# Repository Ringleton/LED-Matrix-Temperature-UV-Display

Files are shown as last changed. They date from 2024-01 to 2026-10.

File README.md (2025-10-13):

# Temperature and UV Index RGB Matrix Display

# Overview
This display utilizes a WIFI connection to read data from a weather server.  The display uses data produced by a Davis Instruments weather server and gets its data populated by its branded weather stations ([www.davisinstruments.com](http://www.davisinstruments.com)).  The source of the data used for this matrix display is produced by a Davis weather station set up in the Cadence neighborhood.  That station transmits data wirelessly to either a legacy data logger and/or a newer display console.  Those two systems separately upload their data to the Davis server, and it is that data that is then retrieved by the matrix display unit every 60 seconds, displaying the current temperature and UV Index.  The Davis server also maintains a web page for each station that shows the weather statistics for each.



This LED matrix display is built using a Raspberry Pi Zero 2 W, single board computer along with an Adafruit RGB matrix “bonnet” plugged into the top of the Pi.  The bonnet converts the Pi’s 3.3V output pins to 5.0V logic along with a socket to connect a cable to the input of one of the two 64 X 32 RGB LED matrix, 3mm pitch (P3) panels.

The Pi’s external connectors are exposed at the rear inset of the enclosure, along with a separate power supply connection (5V, 10A) and a pushbutton that acts as either a reboot or shutdown trigger.  You can connect a video display to the Pi’s mini-HDMI connector and a mouse / keyboard dongle to the Pi’s micro-USB On-The-Go (OTG) port to interact and control the system.  Optionally, you can also use a terminal emulator connected over WIFI.  The Pi uses a Unix-based operating system.  The program itself is written in Python.

To capture the data from the weather station, either a Davis data logger and/or station console is used.  The Davis WeatherLinkIP device is a legacy data collection device that is now obsolete.  It is one of the earlier devices that Davis employed to upload data from a weather station to their server.  As of this writing, the 6313 Console is Davis’ latest product.  This unit is an Android-based tablet display and uploads data to their server.  If both devices are employed concurrently, even though they are receiving the data being transmitted from the same physical weather station, when uploaded, the Davis server treats these as two entirely separate weather stations.  Both produce an almost identical web page summary.  You will find both a “Cadence at the Lakes” (6313 Console) and a “Cadence at The Lakes 2” (WeatherLinkIP) weather station on the Davis map with “2” being the legacy unit’s data.

While both devices upload data every 60 seconds and the corresponding web page summaries are updated immediately, the data can only be read back every 60 seconds without a paid subscription with the legacy device station.  The data from the newer console requires a paid subscription to read the data every 5 minutes or 1 minute.  Otherwise, the free subscription only provides updated data every 15 minutes.  For this reason, while the legacy device continues to work, this display is currently configured to grab that station’s data.  Until it is changed, the webpage data for station “2” and this display should be in almost perfect synchronization.

The program is designed to be able to pull data from either station so should the legacy device eventually fail or no longer be supported on their server, you can reconfigure the display to use the data uploaded from the newer console.  But note that, unless you subscribe (pay) for one of the upgraded plans, the display will show the same information for 15 minutes before it is updated (the temperature may suddenly jump several points) and the data will not be in perfect synchronization with the web page summary of this same station.
# Shutting Down or Restarting
On the rear inset panel just below the power jack, there is a pushbutton.  Momentarily press once to restart the display (takes about 60 seconds) or press and hold for at least two seconds to safely shut down the unit (takes about 20 seconds).  Whenever possible, always use the pushbutton to shut down the unit safely before disconnecting the power.  Note that when first applying power, it will take about 40 seconds before something appears on the display.
# Removing the Display from a Wall
Taking advantage of a wall with alternating vertical panel widths, extending from the rear inset area of the enclosure near the top are two levers that act as locks to prevent easy removal of the display from a wall.  To remove the display, reach from above and slide both levers fully to one side.  Note that one lever should already be pushed fully to one side so just push the other over to the same side.  You should then be able to slightly push the opposite side of the panel up and then pull away from the wall just enough until you can slide both levers fully back towards that side.  Then you should be able to pull the other side of the display slightly up and pull away from the wall and the entire display should then release.

To re-install on the wall, reverse the steps above and once completed, separate and push the one lever away from the other towards its corresponding side of the display.  If locked correctly, you should not be able to push the display upwards to then pull off the wall.

Without the locks installed, just push the entire display slightly up and then pull away from the wall.
# Username and Passwords
The username for this Pi is “cadence” and the password is “atthelakes”.  This will provide you with access to this Pi and the ability to change the WIFI network and the weather station credentials.  If the Pi username or password is ever changed, you will need to record this new information somewhere that an administrator has access to.  If the username and password above do not work, then someone may have already made that change – check with the administrator for the updated information.

The Davis Instruments account information will also need to be known by this display if the account changes or a different station is to be monitored.  The Davis Device ID or API key and secret can all be found under the Davis account.  The Davis account information will also be required to make changes to the WIFI connection of the 6313 Console.

Optionally, a free Adafruit IoT account can be used to monitor display statistics.  This Adafruit feed can be configured to provide an email notification after a configured period of inactivity.  This can alert the administrator that the display has failed or lost its internet connection.  See Adafruit IoT Monitoring below for more information.
# Connecting to the Pi
##
## With WIFI
If the Pi is connected to a WIFI network and you know it’s IP address, use the VNC Viewer application (a terminal emulator) on either a tablet or computer connected to the same WIFI network and enter the Pi’s IP address when prompted.  If you do not know the Pi’s address, you may be able to ping it or use other software to identify its IP. 
## Without WIFI
If the Pi is not connected to a WIFI network -- maybe the network has been removed or password has changed – you will need to connect directly to the Pi itself.  With the Pi removed from the wall and powered off, locate the ports on the rear inset of the display.  Connect an HDMI display to the mini-HDMI port.  Connect an On The Go (OTG) micro-USB cable to the center USB port and connect a wireless mouse / keyboard dongle to that cable.  Then, either connect the 5V, 10A power supply to the 2.1mm barrel jack port or connect a 5V, 4A power supply to the outside USB port on the Pi.  The Pi can be operated from only the USB power supply but if the RGB display is also on, the 4A power supply may not be powerful enough to drive the display and may cause the Pi to report a low voltage condition or it may just hang.

Once you have established the WIFI connection, you may want to revert to using the VNC Viewer application noted above.
# Program Configuration
The following assumes the user has basic knowledge of navigating through the Pi’s folder structure and how to edit a text file as those are beyond the scope of this document.

The display has a few user-configured options such as which Davis weather station to monitor and its operating hours.  To change the configuration, you will need to connect to the Pi using either of the methods noted above.  From the Home directory, navigate to the LED\_matrix folder.  For an existing system, in there you will find a configuration file named “config.json”.  For new installations, there is also a “config.json.sample” file that can be renamed or copied over.  The instructions for that are found further down in the [Installing the Software](README.md#Installing-the-Software) section.

Use a text editor to make any changes.  For example, from a terminal window and in the LED\_matrix folder, type: `sudo nano config.json`

The following options are found:

Property| |Description
--- | --- | ---
|`davis_weatherlinkIP_interface`||These are used for the legacy WeatherLinkIP device.
||`user`|Contrary to its name, this is the “Device ID” (DID) found under the “Device Info” screen when logged into your Davis account.  This is also shown on the back of the WeatherLinkIP device.  If this field is left blank, then the display will use the information and data from the newer console found in the next section.  If this field is not blank, then any information found in the next Console interface section is ignored.
||`password`|This is the same password you use to log into your Davis account.
|`OR_davis_console_interface`||These are for the newer 6313 Console.
||`api_key`|This key and its secret are found under your Davis “Account Information” screen, shown as “API Key V2"
||`api_secret`|
||`station_name`|This name is **case-sensitive** and set via the 6313 Console.  It is currently set to “Cadence at The Lakes”.
|`operating_hours`||Outside of the operating hours, the display will go blank and show only a blinking cursor in the lower right corner.
||`24_hours_per_day`|Set to `true` or `false`.  If false, the next two values are used.
||`on_time`|
||`off_time`|
|`dimmer`||The display can adjust its brightness based on the ambient light levels as detected by an optional light sensor found on the front edge of the display.
||`use_sensor`| If set to `true`, the sensor is used and the remaining options in this section are ignored.  The brightness of the display is adjusted every minute based on the current ambient light level.
||`max_brightness_percent`|Maximum daylight brightness setting.
||`min_brightness_percent`|Minimum nighttime brightness setting.
|`UV`||When the sun is above the horizon, the UV index can be shown on the right side of the display.  When the sun has set, only the day’s high and low temperatures are shown.  When the UV is shown, you can optionally alternate the UV index with the high and low temperatures.
||`show_UV`|Do you want UV displayed?  If you do not have a UV sensor or just don't want UV on this display, set this to `false`.
||`alternate_with_hi_lo_temp`|If set to true, during the daytime, the right side of the display alternates between the UV index and the high and low temperatures.  Otherwise, the UV index is always shown during the day.
||`hi_lo_temp_length_seconds`|During each 60 second period, this is the number of seconds that the high and low temperatures are shown instead of the UV index.
|`adafruit_IO`||The following information is optional.  A free IoT account can be created at Adafruit.com.  Every 10 minutes, this display uploads information about itself, for example, internal CPU temperature, error count and current uptime.  The Adafruit IoT feed can be configured to send an email after a configured amount of inactivity thereby alerting an administrator that the display may be down or has lost WIFI connectivity.
||`user`|Enter your Adafruit username here.
||`key`|Adafruit API key.
||`feed`|Adafruit feed name “key”.
|`locale`||Information for your locale.  Used to determine sunrise, sunset, and temperature colours.
||`latitude`|Enter your latitude here.
||`longitude`|Longitude.
||`horizon`|On the prairies, set this to 0.0 (degrees).  But if you are in a valley, you can increase this setting to best reflect the number of degrees to your horizon in order to get a more accurate sunrise and sunset for your locale.
||`really_hot`|Temperatures above this will be red.
||`really_cold`|Temperatures below this will be purple.
|`use_Celsius`||Set to `true` for Celsius or `false` for Fahrenheit

# Error Messages
If the display encounters any issues with either connectivity or the retrieved data, depending on the issue, it will attempt to automatically recover.  During the recovery period, it may display an error message.

**Network connection error.  Check WiFi.  Will retry...:** The display has lost its WIFI connection.  Check the local WIFI devices.  If WIFI is present but the error does not clear, you may need to restart the display using the optional button located on the rear of the enclosure.  Once WIFI is reestablished, the display will take up to one minute to automatically refresh.   Should you need to connect to a new WIFI network, you will need to manually connect to the Pi using the HDMI and USB connections on the rear of the display and select the new WIFI network.  See [Connecting to the Pi](README.md#Connecting-to-the-Pi) above.

**Outdated data.  Check local transmitter device**: Connectivity between this display and the Davis weather server still exists but the data being returned is more than a few minutes old.  This will also be reflected in the Davis summary web page.  This is most likely due to the local WeatherLinkIP device or the 6313 Console either being powered off or having lost their connection to their local WIFI network.  Check that device and its WIFI network - you do not need to make any changes with the display.  As soon as current data is uploaded again, the display will automatically refresh.

**Network HTTP error: ###:** This could be a server issue.  There is likely nothing you can do to correct this.  The display should recover automatically once the issue is corrected.

**Possible invalid Weatherlink username or password:**  Check the user (Device ID) or password entered in the config.json file.

**Possible invalid Weatherlink station name:** If using the Console interface, verify the weather station name.  Did you just edit it via the Console interface?  The name on the Console interface must match the name in the config.json file, and it is case sensitive.

**JSON key error: 'XXXX’ or JSON error: Expecting value: line X column Y (char Z)**: The data returned by the server is corrupt.  This is likely an intermittent problem with the server and will automatically correct itself.  There is nothing that can be done to correct this on this end. The display should recover automatically once the issue is remedied.
# Preparing the Raspberry Pi
## Installing the Operating System
Should you need to prepare a new Raspberry Pi from scratch, acquire a new micro-SD card (16Gb or more should be sufficient) and use the Raspberry Pi Imager for either a PC or Mac found here: <https://www.raspberrypi.com/software/>

When selecting the operating system, choose the “Raspberry Pi OS with desktop (Recommended)”.  

You may want to pre-edit the configuration options with a default username and password and the local WIFI username and password.  Alternatively, these settings can be edited later.   These installation notes assume a non-default user of “cadence,” but any username is fine if you adjust any reference to “cadence” to that of the user you have chosen.  Record the username and password for any future administrator.

After preparing the micro-SD card, insert it into the Raspberry Pi Zero 2 W.  Connect a mouse/keyboard dongle via a USB connector plugged into the Pi’s center USB port.  Connect a screen via the mini-HDMI connector of the Pi.  Plug a 5V power supply into the outside “PWR” USB connector and power it up.  Optionally, if the RGB matrix bonnet is already installed on top of the Pi, you can connect power to the 2.1mm barrel jack on the bonnet and the Pi will use its power.

The Pi may prompt you for some basic information and will then reboot.  It will then begin updating it’s OS to the latest version.  This may take several minutes.  When complete, it will boot up to a desktop.

If not already performed during the micro-SD card configuration, enter the network configuration area, and set up your local WIFI.

Click on the Raspberry icon on the desktop and select:  Preferences --> Raspberry Pi Configuration.

Under the Interfaces tab, ensure that I2C and optionally, VNC is enabled.  Wait for the VNC icon to appear in the upper right corner.  Reboot if you had to make any changes.

While you can continue to prepare the Pi using your directly connected monitor and mouse/keyboard dongle, if enabled above, you may want to install the Windows or Mac VNC terminal program and connect to the Pi using that.
## Installing the Software
The following steps explain how to install the necessary software for the display operation.  Detailed information about the RGB matrix bonnet and the steps to modify it by soldering a jumper can be found here: <https://learn.adafruit.com/adafruit-rgb-matrix-bonnet-for-raspberry-pi>

The LED-matrix library is copyrighted by Henner Zeller and a more in-depth explanation can be found here: <https://github.com/hzeller/rpi-rgb-led-matrix>

While you can view the links above, the software installation steps for the RGB matrix library files included in the links above are shown here…

Start a terminal window and while in the home folder, enter these commands:

`curl https://raw.githubusercontent.com/adafruit/Raspberry-Pi-Installer-Scripts/main/rgb-matrix.sh >rgb-matrix.sh`

`sudo bash rgb-matrix.sh`

When prompted, select the Adafruit RGB Matrix Bonnet and the Qualtity option.  As noted in their instructions, this step will take several minutes to complete.  The system will prompt you to reboot.

As we are using a jumper to implement the “quality” option on the RGB matrix (see the learn.Adafruit.com link above), the sound card in the Pi must be disabled so as not to interfere.  After the system has rebooted, start a terminal window again and type the following:

`sudo nano /boot/config.txt`

In this file, look for the line containing “dtparam”.  If necessary, edit this line so that it reads:

`dtparam=audio=off`

Press CTRL-X to exit the editor and if changes were made, confirm “Save modified buffer”.

With the latest OS, it is necessary to further disable the sound card by entering the following commands:

`cat <<EOF | sudo tee /etc/modprobe.d/blacklist-rgb-matrix.conf`

\> `blacklist snd_bcm2835`

\> `EOF`

`sudo update-initramfs -u`

You will need to reboot again for the changes above to take effect.

Now that the RGB library files are installed, we will install our Python programs.  After rebooting, start a terminal window again and while in the home folder, enter the following commands:

`git clone https://github.com/Ringleton/LED-Matrix-Temperature-UV-Display.git ./LED_matrix`

`cd LED_matrix`

`sudo pip install -r requirements.txt`

It is now necessary to create a configuration file.  While still in the LED\_matrix folder, type:

`cp config.json.sample config.json`

Edit this file by typing:

`sudo nano config.json`

See the [Program Configuration](README.md#Program-Configuration) section above to make the necessary changes.  Once completed, press CTRL-X to exit the editor and save your changes.

Before setting up the automatic start feature for the display and optional reboot/shutdown button, test the program now by manually launching it.  While you are still in the LED\_matrix folder, type:

`sudo python temp_display.py`

If everything is working correctly, after a few seconds, you should see temperatures shown in the display.  If any error messages appear, you will need to address them.  They will appear on the screen when the program is run interactively but some will also be placed into a file named “logfile.log”.  This log file contains information messages, warning and errors and is overwritten each time the program is started.

To manually terminate the program, press CTRL-C.

NOTE: When launching the program, you may see a warning message suggesting editing the /boot/cmdline.txt file and adding “isolcpus=3” to the very end.  If you see that, from a terminal window, type the following command:

`sudo nano /boot/cmdline.txt`

At the very end of the single line, add a space, followed by `isolcpus=3`

Press CTRL-X to exit and save the file.

You will need to reboot for this change to take effect.  Then see if the warning message has cleared by manually launching the program again from a terminal window:

`cd ~`

`cd LED_matrix`

`sudo python temp_display.py`

# Automatic Start Files
The display also includes a pushbutton that can be used to reboot or shutdown the Pi safely without having to first connect to it.  The monitoring of this pushbutton is performed by a separate program in case the main display program terminates or becomes non-responsive.  

If you want the rear button enabled to allow reboot / shutdown capability, you will need to edit the rc.local file.  From a terminal window, type:

`sudo nano /etc/rc.local`

Immediately above the “exit 0” line, add:

`python /home/cadence/LED_matrix/restart_shutdown.py &`

**Or, if you prepared the Pi using the default "pi" username, type this instead:**

`python /home/pi/LED_matrix/restart_shutdown.py &`

Don’t forget the space and ampersand at the end of the line.  Press CTRL-X to exit and save the file.

To test this, reboot the Pi.  Once it has rebooted, try momentarily pressing the pushbutton on the back of the display enclosure.  The Pi should reboot.  Pressing and holding the button for at least two seconds will cause the Pi to shutdown.  Allow at least 20 seconds before disconnecting the power.

To make the main display program automatically start every time the Pi is powered up or rebooted, you will need to create an autostart file.  Before proceeding, ensure that the display program is running correctly when invoked manually as shown above.

Then from a terminal window, type the following lines:

`cd ~`

`cd .config`

`mkdir autostart`

`cd autostart`

`sudo nano display.desktop`

Enter the following lines:
```
[Desktop Entry]

Type=Application

Name=Display

Exec=bash -c 'cd /home/cadence/LED_matrix && sudo /usr/bin/python /home/cadence/LED_matrix/temp_display.py'
```
**Or, if you prepared the Pi using the default "pi" username, for the last line, type this instead:**

`Exec=bash -c 'cd /home/pi/LED_matrix && sudo /usr/bin/python /home/pi/LED_matrix/temp_display.py'`

Don't forget to include the single quote at the very end of the line!

Press CTRL-X to exit and save your changes.  

To test your autostart file, reboot the Pi – you can use the pushbutton if enabled above – and confirm that the display automatically starts.  It may take up to a minute before you see anything in the display.
# Adafruit IoT Monitoring
The display includes the optional ability to upload internal statistics to an Adafruit IoT feed.  You can set up a free Adafruit account and create a feed.  You can configure the Adafruit feed to provide an email notification after a period of inactivity or when the CPU temperature is exceeded.  This can alert an administrator that the display is down, has lost its WIFI connection or running hot - possible blocked vents or defective fan.

Enter your account and feed information into the config.json file as noted above in the [Program Configuration](README.md#Program-Configuration) section.  The following information is sent to the feed:

**CPU T:**	The internal CPU temperature.  The Pi will withstand temperatures up to 85 degrees Celsius.  As it gets closer to its upper limit, the system will automatically begin to throttle the processor down to try to help the CPU cool back down.

**Err:**  The total number of errors encountered since the program was started.  The program is designed to automatically recover from most errors that it encounters.

**Up:**  The total number of days that the program has been running.

**Mem Use:**  The total percentage of used memory.

**Light:**  The light level from the sensor or -1 if not found.

**Brightness:**  The display brightness percentage level.  Based on either the optional light sensor or the configuration settings with the time of day.

Note: If you are connected to the Pi while the display program is running, pressing the Space Bar will temporarily show the statistics above on the display.
# 3D Files and Display Assembly
This project is published on github.com.  Included in the source code is a folder containing the 3D print files for the display enclosure.  You can either grab these files from the “3D-files” folder on the Pi after the software installation is completed or you can download the files from this link:

<https://github.com/Ringleton/LED-Matrix-Temperature-UV-Display>

The enclosure was printed using ABS print filament which provides UV protection.  There are a total of 15 mounting holes used for the 3 back panels.  Those holes are designed to accept M3 X 3mm brass heat-set inserts.  The main enclosure is available in a full print size but there are also separate left and right files in case your 3D printer cannot support the full size.

There are corresponding 3D files both with and without ventilation panels and a fan insert.  For outdoor use, it is strongly recommended to use the enclosure with ventilation panels along with the optional fan.  These ventilation panels include an internal slot to insert a screen mesh to prevent bugs and other debris from getting inside.  These ventilation panels may need to be occasionally cleaned to remove accumulating debris.

# Optional Light Sensor, Shutdown Button, and Fan
The optional VEML7700 light sensor and restart / shutdown pushbutton are connected to a header on the RGB bonnet – see photos below.  These connect to a 3 X 2 header that is connected to the bonnet's six breakout holes located immediately beside the power jack.  A light tunnel from the front of the display to the sensor is created by inserting a short length of 1/8" acrylic rod into the hole on the left side of the enclosure.

The restart / shutdown button has one side of the pushbutton connected to ground while the other side connects to GPIO 19 (pin 35) on the Pi itself.

For outdoor use, the panel's interior temperature can increase significantly, especially when in direct sunlight.  To protect the CPU from overheating, it is recommended to use the enclosure with ventilation panel and install a fan into the fan insert.  The fan can be connected directly to the ground / 5V supply causing it to operate 24/7.  

Optionally, you can install a fan switch controller and have the fan only operate when the internal CPU temperature reaches a specified level.  This will increase fan life and decrease the debris build-up on the vents.  I used a fan controller made by "8086 Consultancy".  An extra ground line is connected to the controller along with 5V and GPIO 14 via the unused connections on the 3 X 2 header on the bonnet.  The fan is then plugged into the output of the controller.  To enable the fan action, click on the Raspberry icon on the desktop menu and select: Preferences --> Raspberry Pi Configuration --> Performance and then enable the fan, set the Fan GPIO to 14 and the "on" temperature.  I used a setting of 69 so that any CPU temperatures at or above 70 will trigger an email alert.

Looking from the top of the bonnet with the connector towards the right:

|||||
| :- | :- | :- | :- |
|Top Row|<p>Black VEML7700</p><p>Ground</p>|<p>Red VEML7700</p><p>3\.3V</p>|<p>*Optional 5V to fan</p><p>or to fan controller</p>|
|Bottom Row|<p>*Optional fan enable</p><p>to fan controller input</p>|<p>Yellow VEML7700</p><p>SCL</p>|<p>Blue VEML7700</p><p>SDA</p>|









# Parts List

|**Part Description**|**Supplier**|**Part #**|**Qty**|
| :- | :- | :- | :- |
|Raspberry Pi Zero 2 W|Adafruit|5291|1|
|Break-away 0.1" 2x20-pin Strip Dual Male Header|Adafruit|2822|1|
|Micro-SD card|||1|
|64x32 RGB LED Matrix panels - 3mm pitch|Adafruit|2279|2|
|RGB Matrix bonnet for Raspberry Pi|Adafruit|3211|1|
|2x8 IDC ribbon cable, 12"|Adafruit|4170|1|
|Right angle VEML7700 light sensor|Adafruit|5378|1|
|STEMMA QT / Qwiic JST SH 4-pin Cable with<br>Premium Female Sockets - 150mm Long|Adafruit|4397|1|
|5V 10A switching power supply|Adafruit|658|1|
|Right angle 2x3 connector header|DigiKey|952-2092-ND|1|
|2\.1mm power plug with cable|DigiKey|839-1246-ND|1|
|Connector jack panel mount 5.5x2.1mm|DigiKey|839-1580-ND|1|
|Pushbutton switch SPST-NO 3A|DigiKey|EG1900-ND|1|
|*Optional* Axial fan 30 X 8mm 5VDC|DigiKey|1528-1904-ND|1|
|*Optional* Fan controller|PiShop.ca|1915|1|
|*Optional* Pi4 heat sink set (use the lowest profile heat sink)|DigiKey||1|
|3D-printed enclosure|||1|
|M2.5 & M3.0 nuts/bolts/spacers|||1|
|M3 X 3mm heat set inserts|Adafruit|4256|15|

# Davis Weather Station Devices and Account Information
The weather station at Cadence uses the following Davis Instruments devices:

- Wireless Vantage Pro 2 Weather Station 6252
- Solar-powered wireless sensor transmitter 6332 (used for the anemometer)
- Solar radiation sensor 6450
- UV sensor 6490
- WeatherLinkIP data logger / transmitter 6555
- WeatherLink Console 6313

The data is uploaded to the Davis WeatherLink.com site and this matrix display uses the Davis API to grab that data from their servers.  See the [Overview](README.md#Overview) section at the beginning of this document for more information.

Anyone can set up a free Davis account where you can monitor weather stations from around the world.  Optionally, you can upload weather data from  your weather station and share it with others.  At the time of this writing, both a legacy 6555 WeatherLinkIP data collector and the newer Davis 6313 Console are both being employed to upload data for Cadence and are treated as two separate weather stations even though the data for each is being transmitted by a single physical station device.

One advantage of the legacy device is that you can download the data via the API and that data is up to the minute, even with a non-subscription account.  Using the data from the newer console is available up to the minute only with a paid subscription.  Otherwise, that data is only updated every 15 minutes.

The legacy device plugs into a network router with a wired connection.  You can configure it using the Davis WeatherLink software for either Windows or a Mac.  This software download is available from Davis if you are logged in with your free Davis account.  Note that the software is very outdated but still works.  On a Windows system, you may have to “Run as Administrator”.

The newer Console connects to your local network over WIFI.  The configuration of that is performed through the Console itself using your Davis account username and password.

Weather station data from around the world is uploaded to the Davis server.  You can access your data and that of other stations via the WeatherLink.com site, your display console or the Davis Weather app, also available for free download.

When logged into your Davis account on the weatherlink.com website, you can also let someone see your weather station data via various URL’s without them needing to sign up for a Davis account.  You can access these URL’s via the “Share and Uploads” button under your account.  At the time of writing, one of those URL’s for the weather station data being sent by the console at Cadence is: <https://www.weatherlink.com/embeddablePage/show/17a85d105372405483298eef95e886b6/summary>

If later, a new Davis account is created and the physical weather station devices are moved over to that account, the URL links will likely also change.

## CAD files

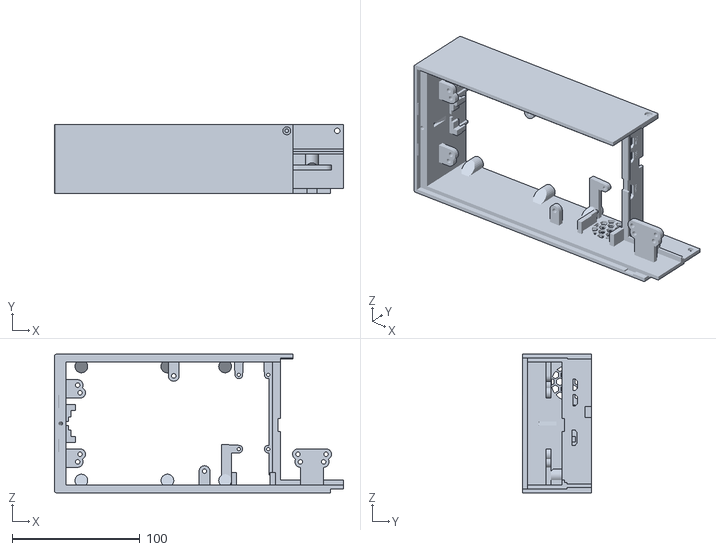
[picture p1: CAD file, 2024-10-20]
3D_files/Dual Matrix Main Enclosure Left with Vents.stl
225.8 x 54.0 x 108.4

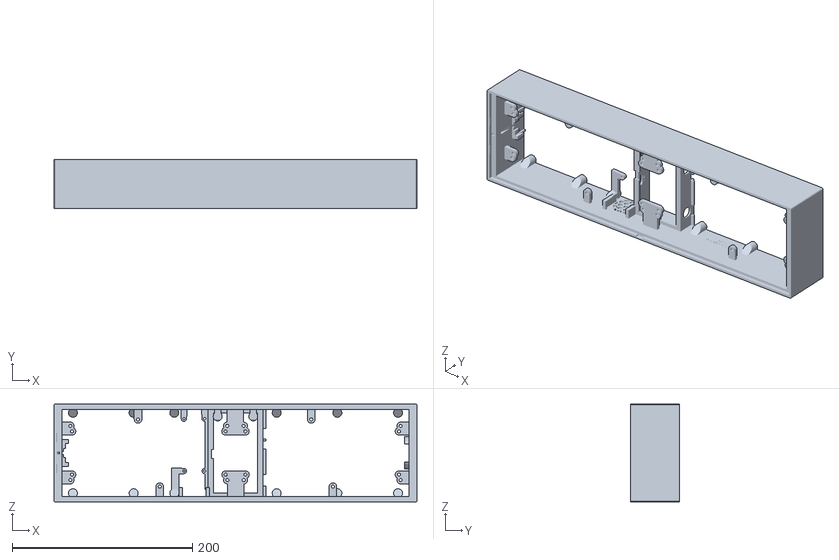
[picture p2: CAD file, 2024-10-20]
3D_files/Dual Matrix Main Enclosure One Piece with Vents.stl
402.3 x 54.0 x 108.4

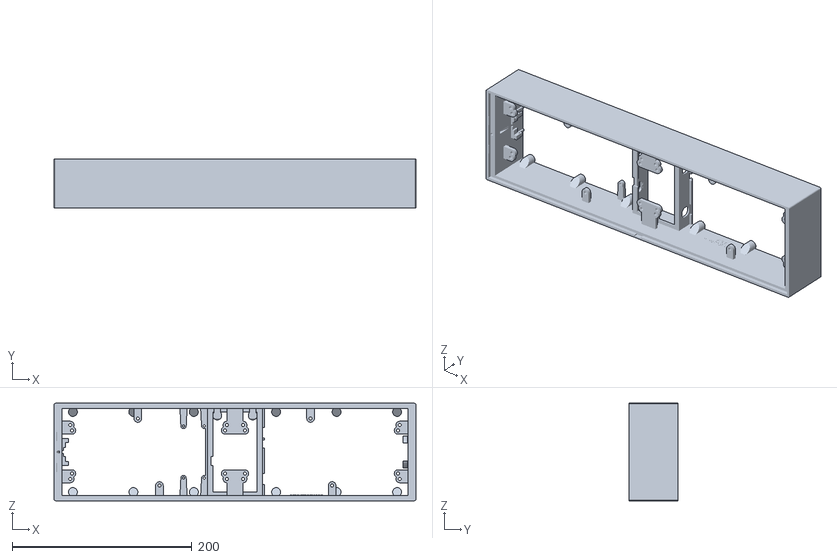
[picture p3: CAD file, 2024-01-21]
3D_files/Dual Matrix Main Enclosure One Piece.stl
402.4 x 54.0 x 108.4

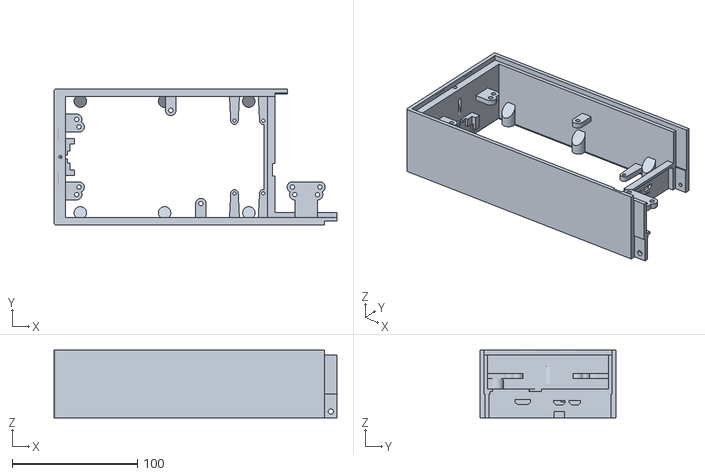
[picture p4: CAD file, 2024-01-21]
3D_files/Dual Matrix Main Enclosure Left.stl
225.8 x 108.4 x 54.0

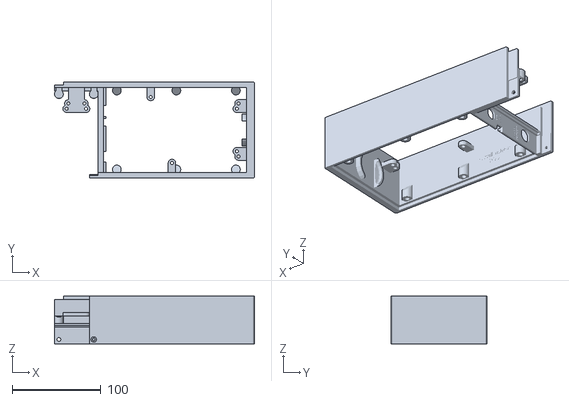
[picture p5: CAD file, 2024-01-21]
3D_files/Dual Matrix Main Enclosure Right.stl
225.9 x 108.4 x 54.0

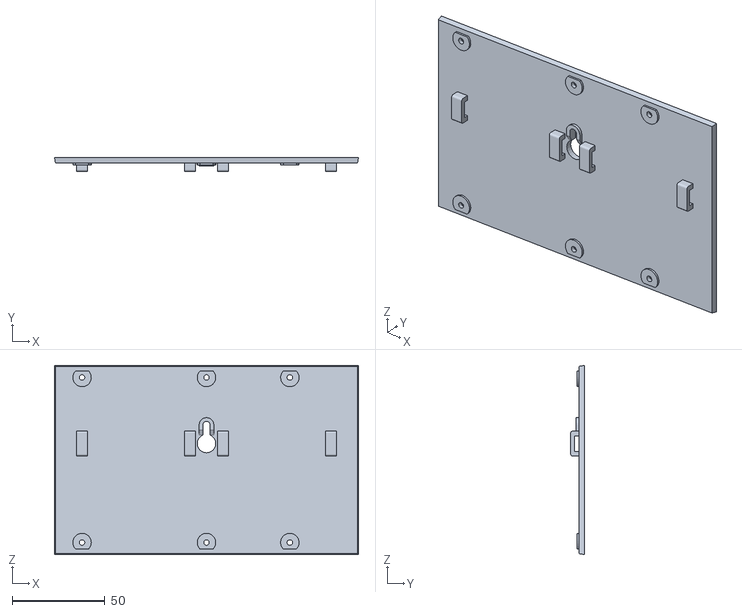
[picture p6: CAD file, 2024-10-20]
3D_files/Dual Matrix Large Back Panel - Vent Side.stl
164.3 x 7.40 x 102.2

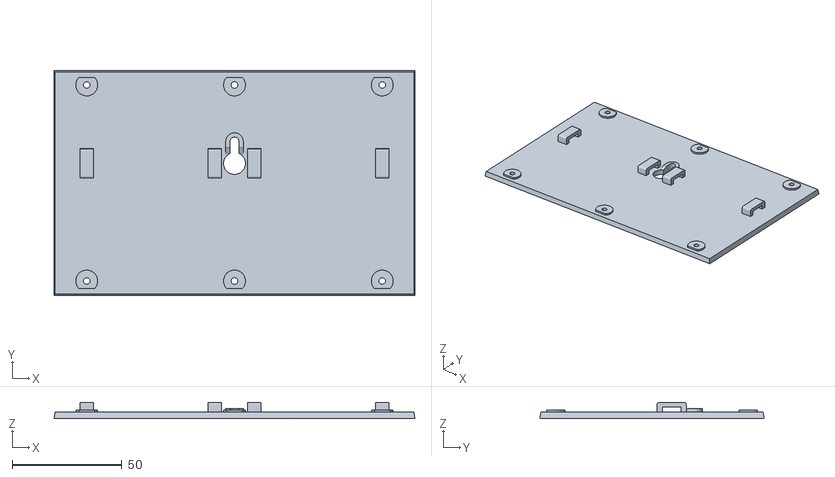
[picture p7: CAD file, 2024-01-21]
3D_files/Dual Matrix Large Back Panel.stl
164.3 x 102.2 x 7.40

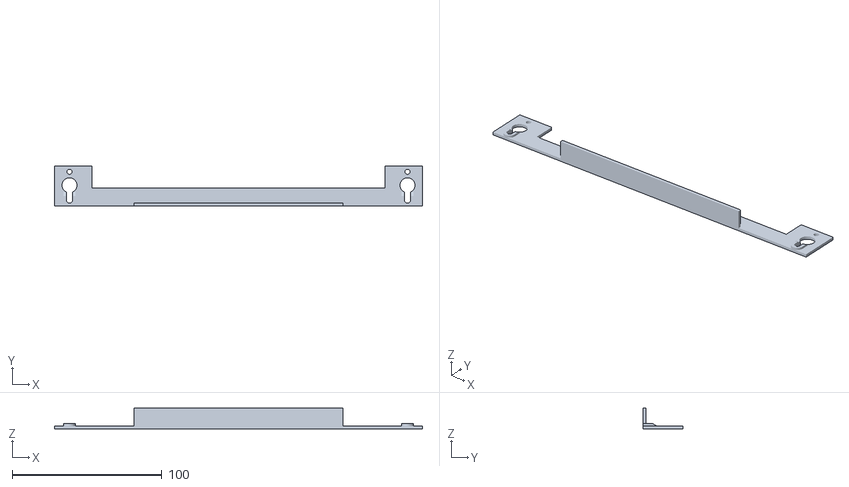
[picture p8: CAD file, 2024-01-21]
3D_files/Dual Matrix Mounting Template.stl
245.9 x 27.0 x 14.0

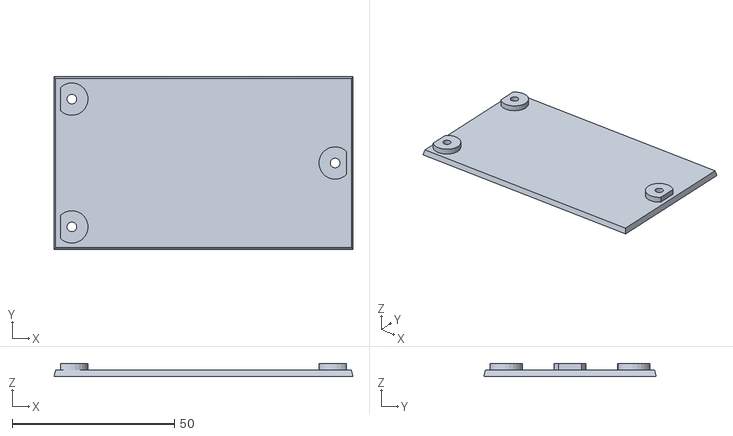
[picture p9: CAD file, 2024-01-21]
3D_files/Dual Matrix Small Back Panel.stl
92.2 x 53.2 x 4.00

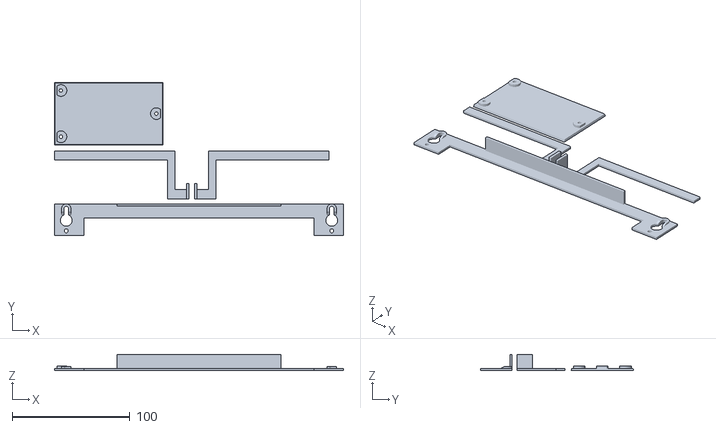
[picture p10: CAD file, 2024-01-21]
3D_files/Dual Matrix Misc Parts.stl
245.9 x 130.4 x 14.0

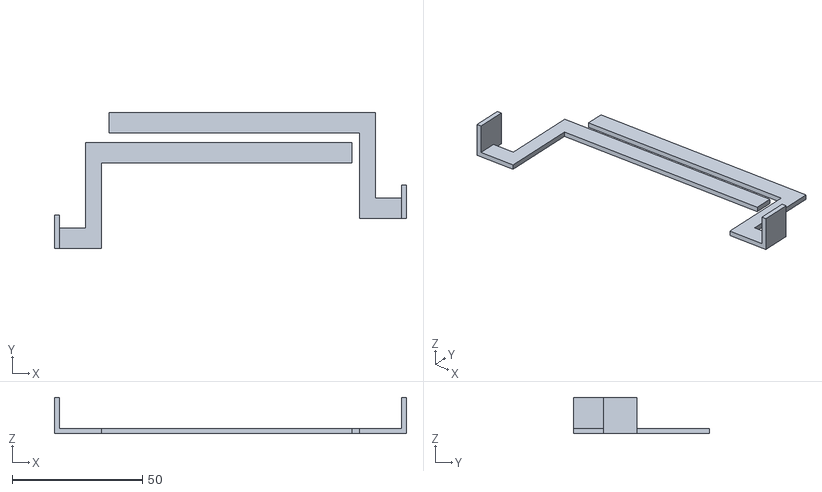
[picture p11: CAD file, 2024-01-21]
3D_files/Dual Matrix Mounting Locks.stl
135.3 x 52.4 x 14.0

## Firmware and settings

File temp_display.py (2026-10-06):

# LED matrix temperature / UV display

# MIT License
# Copyright (c) 2026 by Russell Ingleton

from time import sleep
from datetime import datetime
import os
import sys
import json
import colorsys
import ryb2rgb
import requests
from requests.exceptions import ConnectionError
import threading
import argparse
from rgbmatrix import RGBMatrix, RGBMatrixOptions, graphics
import board
import adafruit_veml7700
import busio
import ephem
import textwrap
import logging
import shutil
import subprocess

# All of these are for various testing
import pynput
from pynput import keyboard 
import functools
import psutil  # for memory testing
from gpiozero import CPUTemperature  # for testing.  CPU temperature monitoring

# For Adafruit IoT feed that montiors CPU temp but also acts as a warning
# if the feed stops receiving information
from Adafruit_IO import Client, RequestError


def args():
    parser = argparse.ArgumentParser()

    # Options for the rpi-rgb-led-matrix library
    parser.add_argument("--led-rows", action="store", help="Display rows. 16 for 16x32, 32 for 32x32. (Default: 32)",
                        default=32, type=int)
    parser.add_argument("--led-cols", action="store", help="Panel columns. Typically 32 or 64. (Default: 64)",
                        default=64, type=int)
    parser.add_argument("--led-chain", action="store", help="Daisy-chained boards. (Default: 2)", default=2, type=int)
    parser.add_argument("--led-parallel", action="store",
                        help="For Plus-models or RPi2: parallel chains. 1..3. (Default: 1)", default=1, type=int)
    parser.add_argument("--led-pwm-bits", action="store", help="Bits used for PWM. Range 1..11. (Default: 11)",
                        default=11, type=int)
    parser.add_argument("--led-brightness", action="store", help="Sets brightness level. Range: 1..100. (Default: 100)",
                        default=100, type=int)
    parser.add_argument("--led-gpio-mapping", help="Hardware Mapping: regular, adafruit-hat, adafruit-hat-pwm",
                        default='adafruit-hat-pwm', choices=['regular', 'adafruit-hat', 'adafruit-hat-pwm'], type=str)
    parser.add_argument("--led-scan-mode", action="store",
                        help="Progressive or interlaced scan. 0 = Progressive, 1 = Interlaced. (Default: 1)", default=1,
                        choices=range(2), type=int)
    parser.add_argument("--led-pwm-lsb-nanoseconds", action="store",
                        help="Base time-unit for the on-time in the lowest significant bit in nanoseconds. (Default: 130)",
                        default=130, type=int)
    parser.add_argument("--led-pwm-dither-bits", action="store",
                        help="Time dithering of lower bits (Default: 0)",
                        default=0, type=int)
    parser.add_argument("--led-show-refresh", action="store_true",
                        help="Shows the current refresh rate of the LED panel.")
    parser.add_argument("--led-slowdown-gpio", action="store",
                        help="Slow down writing to GPIO. Range: 0..4. (Default: 1)", default=2, choices=range(5),
                        type=int)
    parser.add_argument("--led-limit-refresh", action="store",
                        help="Limit refresh rate to this frequency in Hz. Useful to keep a constant refresh rate on loaded system. 0=no limit. Default: 0",
                        default=150, type=int)
    parser.add_argument("--led-no-hardware-pulse", action="store", help="Don't use hardware pin-pulse generation.")
    parser.add_argument("--led-rgb-sequence", action="store",
                        help="Switch if your matrix has led colors swapped. (Default: RGB)", default="RGB", type=str)
    parser.add_argument("--led-pixel-mapper", action="store", help="Apply pixel mappers. e.g \"Rotate:90\"", default="",
                        type=str)
    parser.add_argument("--led-row-addr-type", action="store",
                        help="0 = default; 1 = AB-addressed panels; 2 = direct row select; 3 = ABC-addressed panels; 4 = ABC Shift + DE direct",
                        default=0, type=int, choices=[0, 1, 2, 3, 4])
    parser.add_argument("--led-multiplexing", action="store",
                        help="Multiplexing type: 0 = direct; 1 = strip; 2 = checker; 3 = spiral; 4 = Z-strip; 5 = ZnMirrorZStripe; 6 = coreman; 7 = Kaler2Scan; 8 = ZStripeUneven. (Default: 0)",
                        default=0, type=int)

    parser.add_argument("--led-panel-type", action="store",
                        help="Needed to initialize special panels. Supported: 'FM6126A'", default="", type=str)
    parser.add_argument("--led-no-drop-privs", dest="drop_privileges",
                        help="Don't drop privileges from 'root' after initializing the hardware.", action='store_false')
    parser.set_defaults(drop_privileges=True)

    return parser.parse_args()


def led_matrix_options(args):
    options = RGBMatrixOptions()

    if args.led_gpio_mapping != None:
        options.hardware_mapping = args.led_gpio_mapping

    options.rows = args.led_rows
    options.cols = args.led_cols
    options.chain_length = args.led_chain
    options.parallel = args.led_parallel
    options.row_address_type = args.led_row_addr_type
    options.multiplexing = args.led_multiplexing
    options.pwm_bits = args.led_pwm_bits
    options.brightness = args.led_brightness
    options.pwm_lsb_nanoseconds = args.led_pwm_lsb_nanoseconds
    options.led_rgb_sequence = args.led_rgb_sequence
    options.panel_type = args.led_panel_type
    options.limit_refresh_rate_hz = args.led_limit_refresh
    try:
        options.pixel_mapper_config = args.led_pixel_mapper
    except AttributeError:
        logging.critical('Your compiled RGB Matrix Library is out of date.\n'
                         '                     The --led-pixel-mapper argument will not work until it is updated.')
        
    if args.led_show_refresh:
        options.show_refresh_rate = 1

    if args.led_slowdown_gpio != None:
        options.gpio_slowdown = args.led_slowdown_gpio

    if args.led_no_hardware_pulse:
        options.disable_hardware_pulsing = True

    if not args.drop_privileges:
        options.drop_privileges = False

    # Must force this to False to allow the VEML7700 light sensor to work.
    options.drop_privileges = False

    return options


class Config:
    def __init__(self):

        filename = "config.json"

        if os.path.isfile(filename):
            try:
                jdata = json.load(open(filename))
            except json.decoder.JSONDecodeError as err:
                logging.critical('Invalid json file: %s', err)
                exit(1)
        else:
            logging.critical('Could not find configuration file: %s', filename)
            exit(1)

        # If the WeatherLinkIP device is being used for uploading then
        #   the V1 API data is refreshed every minute.  Use it.
        self.davis_user = jdata["davis_weatherlinkIP_interface"]["user"]
        self.davis_password = jdata["davis_weatherlinkIP_interface"]["password"]

        # Otherwise, use the data uploaded from the newer console.
        # This data is refreshed every 15 minutes (free subscription)
        #   or every 5 or 1 minute intervals (paid subscription)
        self.davis_key = jdata["OR_davis_console_interface"]["api_key"]
        self.davis_secret = jdata["OR_davis_console_interface"]["api_secret"]
        self.davis_station_name = jdata["OR_davis_console_interface"]["station_name"]

        if self.davis_user == "" and self.davis_key == "":
            logging.critical('You must specify user account credentials for at least one interface in the configuration file: %s',
                             filename)
            exit(1)

        self.op_hours_24_hours_per_day = jdata["operating_hours"]["24_hours_per_day"]
        try:
            self.open_at = datetime.strptime(jdata["operating_hours"]["on_time"], '%H:%M').time()
            self.closed_at = datetime.strptime(jdata["operating_hours"]["off_time"], '%H:%M').time()
        except ValueError:
            logging.critical('Invalid operating hours in configuration file: %s', filename)
            exit(1)

        self.use_sensor = jdata["dimmer"]["use_sensor"]
        self.max_brightness_percent = jdata["dimmer"]["max_brightness_percent"]
        if self.max_brightness_percent > 100:
            self.max_brightness_percent = 100
        self.min_brightness_percent = jdata["dimmer"]["min_brightness_percent"]
        if self.min_brightness_percent < 0:
            self.min_brightness_percent = 0

        self.show_UV = jdata["UV"]["show_UV"]
        self.show_temp_with_UV = jdata["UV"]["alternate_with_hi_lo_temp"]
        self.hi_lo_temp_length_seconds = jdata["UV"]["hi_lo_temp_length_seconds"]
        # Main loop repeats every 60 seconds.  So the high/lo temp display must be less than that.  Let's max it at 55 seconds.
        if self.hi_lo_temp_length_seconds > 55:
            self.hi_lo_temp_length_seconds = 55

        # Using Adafruit IO feed to upload statistics and monitor if down.
        self.adafruitIO_user = jdata["adafruit_IO"]["user"]
        self.adafruitIO_key = jdata["adafruit_IO"]["key"]
        self.adafruitIO_feed = jdata["adafruit_IO"]["feed"]

        # Longitude, latitude location.  Used to determine sunrise / sunset.
        self.my_location_lat = str(jdata["locale"]["latitude"])
        self.my_location_lon = str(jdata["locale"]["longitude"])
        self.my_location_horizon = str(jdata["locale"]["horizon"])

        # This sets the max and min temperatures for what will be the most red (hot) and
        # most purple (cold) colors.  Values beyond these will stay at their max color.
        # Set appropriately for your locale
        self.really_hot = jdata["locale"]["really_hot"]
        self.really_cold = jdata["locale"]["really_cold"]
        
        self.use_Celsius = jdata["use_Celsius"]


class Data:
    def __init__(self, config, matrix):
        self.config = config
        self.matrix = matrix

        self.temp_now = None
        self.UV = None
        self.show_hi_low_temp = False
        self.after_hours = False  # to keep track of opening / closing hours
        self.error_count = 5  # to keep track of consecutive API failures
        self.master_error_count = 0  # for testing purposes.  Overall # of API errors.  Prints in log file.
        self.start_time = datetime.now()

        # timer threads
        self.timer_main = None
        self.timer_blink = None
        self.timer_show_UV = None

        self.canvas = self.matrix.CreateFrameCanvas()

        # Load our fonts
        self.font_small = graphics.Font()
        self.font_small.LoadFont("./fonts/4x6.bdf")
        self.font_med = graphics.Font()
        self.font_med.LoadFont("./fonts/8x13B.bdf")
        self.font_large = graphics.Font()
        self.font_large.LoadFont("./fonts/Helvetica38.bdf")
        self.font_msg = graphics.Font()
        self.font_msg.LoadFont("./fonts/7x13.bdf")

        # Used for text titles
        self.title_color = graphics.Color(255, 255, 255)  # white

        filename = "high-lows.data"

        if os.path.isfile(filename):
            with open(filename, "r") as file:
                data = file.read().replace('\n', '')
                self.hi_low_date, self.temp_high, self.temp_low = map(float, data.split(" "))

        else:  # no file.  Fake hi/low date to be outdated.
            self.hi_low_date = datetime.now().timetuple().tm_yday - 1
            self.temp_high = self.temp_low = None

        self.light = None
        self.lux_sensor_available = False 
        if self.config.use_sensor:
            try:
                self.i2c = board.I2C()

                # Grab first reading to ensure sensor is available
                self.sensor = adafruit_veml7700.VEML7700(self.i2c)
                self.lux_sensor_available = True

            except:
                logging.warning('Light sensor not found or not connected, falling back to software mode.')

        # create a REST client instance for the IoT feed
        self.io_client = Client(self.config.adafruitIO_user, self.config.adafruitIO_key)
        
        self.cputemp=CPUTemperature


# This function will get all temperature values and store for use
def get_temp(data):

    # Use the V1 API if a username was specified in the config file.
    if data.config.davis_user != "":
        DAVIS_V1_API_BASE = "https://api.weatherlink.com/v1/NoaaExt.json?user="
        DAVIS_V1_API_URL = DAVIS_V1_API_BASE + data.config.davis_user + "&pass=" + data.config.davis_password

        try:
            with requests.get(DAVIS_V1_API_URL, timeout=10) as response:

                if response.status_code == 200:
                    if response.text == 'Invalid Request!':
                        data.error_count += 1
                        data.master_error_count += 1
                        logging.critical('Consecutive error count: %d.  Total error count: %d.\n'
                                      '                     Possible invalid Davis WeatherlinkIP username or password.\n'
                                      '                     Verify credentials and check config.json file.',
                                      data.error_count, data.master_error_count)

                        # This is likely a permanent error until fixed.  We will always return a failure regardless as to error count
                        return (0, "Possible invalid Weatherlink user name or password")

                    else:  # We have a valid V1 response request
                        try:
                            results = response.json()
                            
                            # Set defaults in case no valid temp or UV readings returned.
                            data.temp_now = data.UV = None
                            data.temp_high = -999
                            data.temp_low = 999
                            
                            try:
                                age = int(results['davis_current_observation']['observation_age'])
                                if age > (5 * 60):  # if data is older than 5 minutes
                                    data.error_count += 1
                                    data.master_error_count += 1
                                    logging.warning('Consecutive error count: %d.  Total error count: %d.\n'
                                                    '                     Outdated data.  Data is %d minutes old.\n'
                                                    '                     Check the local Davis Weatherlink transmitter device and its network\n'
                                                    '                     connectivity.  There is nothing wrong with this display system!',
                                                    data.error_count, data.master_error_count, int(age / 60))

                                    # The first time we are here, data is already 5 minutes old so waiting 5 times = 10 minutes to error.
                                    if data.error_count > 5:
                                        return (0, "Outdated data.  Check local transmitter device")

                                    # else we will just fall through and continue to grab the data even though it will be the same as last

                                # if not an age issue, then reset our consecutive error count back to zero.
                                else:
                                    data.error_count = 0
                                    
                                # Get current temp
                                try:
                                    if data.config.use_Celsius:
                                        data.temp_now = float(results['temp_c'])
                                    else:
                                        data.temp_now = float(results['temp_f'])
                                        
                                # Key could be missing if battery on main station is dead
                                # If so, continue without error.  Value will be displayed as "---"
                                except KeyError:
                                    pass

                                try:
                                    data.temp_high = float(results['davis_current_observation']['temp_day_high_f'])
                                    data.temp_low = float(results['davis_current_observation']['temp_day_low_f'])

                                    if data.config.use_Celsius:
                                        data.temp_high = round((data.temp_high - 32) * 5 / 9, 1)
                                        data.temp_low = round((data.temp_low - 32) * 5 / 9, 1)

                                except KeyError:
                                    pass

                                try:
                                    data.UV = float(results['davis_current_observation']['uv_index'])
                                    
                                except KeyError:
                                    pass

                                return (1, "Success")

                            except KeyError as err:
                                data.error_count += 1
                                data.master_error_count += 1
                                logging.error('Consecutive error count: %d.  Total error count: %d.\n'
                                              '                     There was json error in the Davis data feed trying to read key: %s',
                                              data.error_count, data.master_error_count, err)

                                if data.error_count > 5:
                                    return (0, f"JSON key error: {err}")
                                else:
                                    return (1, f"JSON key error: {err}")

                        except json.decoder.JSONDecodeError as err:
                            data.error_count += 1
                            data.master_error_count += 1
                            logging.error('Consecutive error count: %d.  Total error count: %d.\n'
                                          '                     Invalid JSON file: %s',
                                          data.error_count, data.master_error_count, err)

                            if data.error_count > 5:
                                return (0, f"JSON error: {err}")
                            else:
                                return (1, "Warning")

                else:  # we got a V1 response code != 200
                    data.error_count += 1
                    data.master_error_count += 1
                    logging.error('Consecutive error count: %d.  Total error count: %d.\n'
                                  '                     HTTP Error: %s',
                                  data.error_count, data.master_error_count, response.status_code)

                    if data.error_count > 5:
                        return (0, f"Network HTTP error: {response.status_code}")
                    else:
                        return (1, "Warning")
            # End with requests.get()...

        except requests.exceptions.ConnectionError as err:

            # Internet / network is lost
            data.error_count += 1
            data.master_error_count += 1
            logging.error('Consecutive error count: %d.  Total error count: %d.\n'
                          '                     Encountered a network connection error: %s',
                          data.error_count, data.master_error_count, err)

            if data.error_count > 10:
                # Giving up on restarting WiFi.  Let's reboot
                logging.critical('No WiFi.  Rebooting Pi')
                os.system("sudo shutdown -r now")

            if data.error_count > 5:
                # In case dead WiFi due to Pi, will try restarting WiFi...
                subprocess.run(["sudo", "ip", "link", "set", "wlan0", "down"], check=True)
                sleep(2)
                subprocess.run(["sudo", "ip", "link", "set", "wlan0", "up"], check=True)
                
                return (0, f"Network connection error.  Check WiFi Will retry...")
            else:
                return (1, "Warning")

    else:  # V1 username was blank so use V2 interface
        DAVIS_V2_API_BASE = "https://api.weatherlink.com/v2/stations?"
        DAVIS_V2_API_URL = DAVIS_V2_API_BASE + "api-key=" + data.config.davis_key

        try:
            with requests.get(
                headers={
                    "X-Api-Secret": data.config.davis_secret
                },
                url=DAVIS_V2_API_URL,
                verify=True, timeout=10) as response:
            
                if response.status_code == 200:
                    try:
                        results = response.json()
                        try:
                            station_id = ''
                            # If only one station on this WeatherLink account, use it regardless of name match
                            if len(results) == 1:
                                station_id = results['stations'][0]['station_id']
                            else:  # Loop through all stations until we find the matching one
                                for i in range(len(results)):
                                    if results['stations'][i]['station_name'] == data.config.davis_station_name:
                                        # Grab the internal ID for that station to be used below
                                        station_id = results['stations'][i]['station_id']
                                        break
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

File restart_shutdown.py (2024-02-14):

import RPi.GPIO as GPIO
from time import sleep
import os
from datetime import datetime

monitor_pin = 19

GPIO.setmode(GPIO.BCM)

GPIO.setup(monitor_pin, GPIO.IN, pull_up_down = GPIO.PUD_UP)

def Shutdown_or_Restart(channel):

    # Ignore false positives (static?)
    sleep(0.05)
    # If still showing pressed (state=0) after 50ms, then this is a real button press.
    if GPIO.input(monitor_pin) == 0:
        # We now wait two seconds then see what we've got.
        sleep(2)
        if GPIO.input(monitor_pin) == 1:  # not pressed now
            # Short press < 2 seconds so restart
            os.system("sudo shutdown -r now")
    
        else: # still pressed
            # Long press > 2 seconds so shutdown (halt)
            os.system("sudo shutdown -h now")
    
GPIO.add_event_detect(monitor_pin, GPIO.FALLING, callback = Shutdown_or_Restart, bouncetime = 50)

while True:
    sleep(1)

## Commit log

2024-01-25 Fixed Adafruit error exception, 6/9 font change
    [temp_display.py]
2024-02-14 Ignore false positives causing reboots
    [restart_shutdown.py]
2024-10-20 Updated README.md
    Added information on the optional 3D prints containing ventilation panels. And minor edits.
2024-10-20 Additional 3D files with ventilation
    [Dual Matrix Large Back Panel - Vent Side.stl, Dual Matrix Main Enclosure Left with Vents.stl, Dual Matrix Main Enclosure One Piece with Vents.stl]
2024-11-23 Improved error trapping for no UV key
    [temp_display.py]
2025-03-05 Fixed memory leak. Improved display when sensors missing due to low battery. Minor logging changes.
    [temp_display.py]
2025-10-13 Update README.md
    Noted optional fan and fan controller, minor edits.
2026-10-06 Memory leak fixes and reboot after 5 minutes with no Wifi
    [temp_display.py]
